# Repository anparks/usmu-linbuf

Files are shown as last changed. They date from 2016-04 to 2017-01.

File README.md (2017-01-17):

This repository contains hardware design files for the uSMU LINBUF project, a test instrument for measuring the time-domain current consumption of low-power loads.

Hardware project files and libraries are in altium/* and are compatible with Altium Designer 14+.

The user's manual is at doc/manual.html, and a PDF printout of the schematics are at doc/schematic.pdf.

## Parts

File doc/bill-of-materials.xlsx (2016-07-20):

Comment | Description | Designator | Footprint | Quantity | Source PN | Detailed Description
Test Point | Test Point, large or small foot prints | AUX_IN, AUX_OUT, EXT_REF | Test Point - Large | 3 | 36-5013-ND | TEST POINT PC MULTI PURPOSE ORG
 |  | GND2, GND4, GND5, GND6 | Test Point - Large | 4 | 36-5011-ND | TEST POINT PC MULTI PURPOSE BLK
 |  | HI_SENSE, LO_SENSE | Test Point - Large | 2 | 36-5010-ND | TEST POINT PC MULTI PURPOSE RED
Cap | Ceramic Capacitor (Surface Mount) | C1, C2 | 1210-W | 2 | 587-2832-1-ND | CAP CER 10UF 35V X5R 1210
Cap | Ceramic Capacitor (Surface Mount) | C3, C4 | ‘0805 | 2 | 587-2400-1-ND | CAP CER 1UF 50V X5R 0603
Cap | Ceramic Capacitor (Surface Mount) | C5 | ‘0805 | 1 | 587-1994-1-ND | CAP CER 0.1UF 35V X5R 0402
2STD16654T4 | STMicroelectronics NPN BJT High Power | Q1 | TO-252 | 1 | 497-5236-1-ND | TRANS NPN 65V 6A DPAK
Res2 | Resistor | Rbuf1 | AXIAL-0.4 | 1 | CMF1.0HHCT-ND | RES 1 OHM 1/2W 1% AXIAL
Res2 | Resistor | Rbuf2 | AXIAL-0.4 | 1 | CMF1.0HHCT-ND | RES 1 OHM 1/2W 1% AXIAL
Res2 | Resistor | Rbuf3 | AXIAL-0.4 | 1 | CMF10.0HFCT-ND | RES 10.0 OHM 1/2W 1% AXIAL
Res2 | Resistor | Rbuf4 | AXIAL-0.4 | 1 | CMF20.0HFCT-ND | RES 20.0 OHM 1/2W 1% AXIAL
Res2 | Resistor | Rbuf5, Rs1 | AXIAL-0.4 | 2 | CMF100HBCT-ND | RES 100 OHM 1/2W 0.1% AXIAL
Res2 | Resistor | Rs2 | AXIAL-0.4 | 1 | CMF200HFCT-ND | RES 200 OHM 1/2W 1% AXIAL
Res2 | Resistor | Rs3 | AXIAL-0.4 | 1 | CMF1.0KHBCT-ND | RES 1.0K OHM 1/2W 0.1% AXIAL
Res2 | Resistor | Rs4 | AXIAL-0.4 | 1 | CMF2.0KHBCT-ND | RES 2.0K OHM 1/2W 0.1% AXIAL
Res2 | Resistor | Rs5 | AXIAL-0.4 | 1 | CMF10.0KHLCT-ND | RES 10.0K OHM 1/2W .1% AXIAL
JS202011CQN | 6-pin DPDT (tied) Slide Switch | SW1, SW2, SW3, SW4, SW5, SW6, SW7 | JS202011CQN | 7 | 401-2001-ND | SWITCH SLIDE DPDT 300MA 6V
MC78M06 | 500mA Positive Voltage Regulator | U1 | TO-252 | 1 | MC78M06CDTRKGOSCT-ND | IC REG LDO 6V 0.5A DPAK
OPA1492 | OPAx192 Op-Amp Texas Instruments | U2 | 14-SOIC-TI | 1 | 296-43159-1-ND | IC OPAMP RRI/O 14SOIC
3339H | Bourns 4-turn Trimpot | VR1 | 3339H | 1 | 3339H-103LF-ND | TRIMMER 10K OHM 0.5W PC PIN
BANANA | Banana plug | GND1, GND3 | BANANA | 2 | BP-B | BANANA JACK BINDING POST, BLACK
 |  | VDD, VOUT1 | BANANA | 2 | BP-R | BANANA JACK BINDING POST, RED

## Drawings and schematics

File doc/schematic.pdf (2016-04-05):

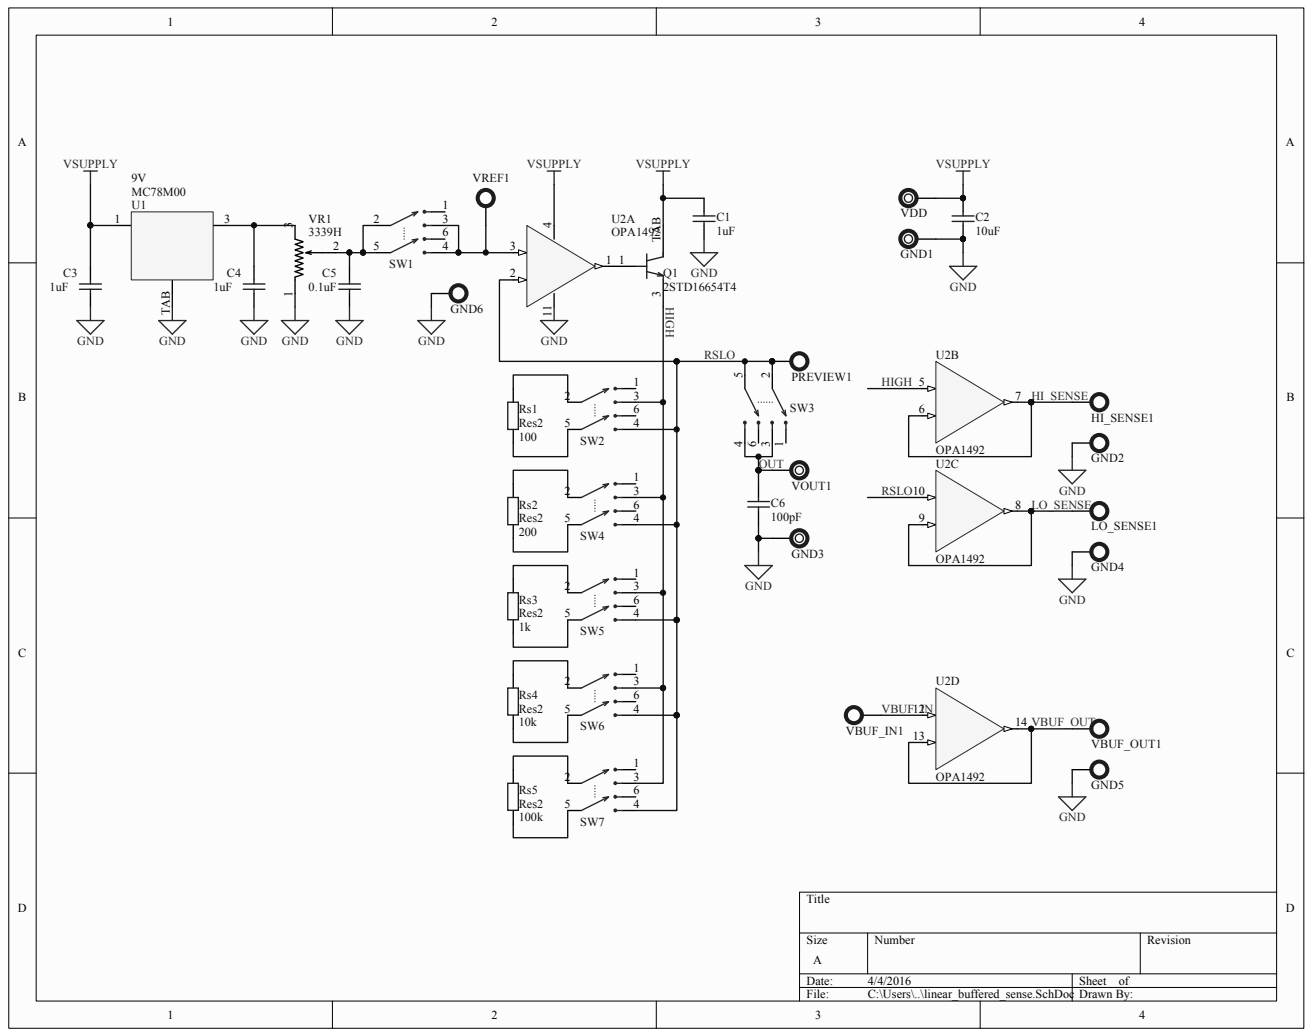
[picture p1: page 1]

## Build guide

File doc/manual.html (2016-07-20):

# uSMU LINBUF User's Guide

github.com/anparks/usmu-linbuf

Click for Schematics

Click for a bill of materials

The uSMU (micro- Source Measure Unit) tools are intended to allow current measurement with a high temporal resolution and high dynamic range.

The uSMU LINBUF tool is a simple implementation of the uSMU with decent dynamic range and good precision.

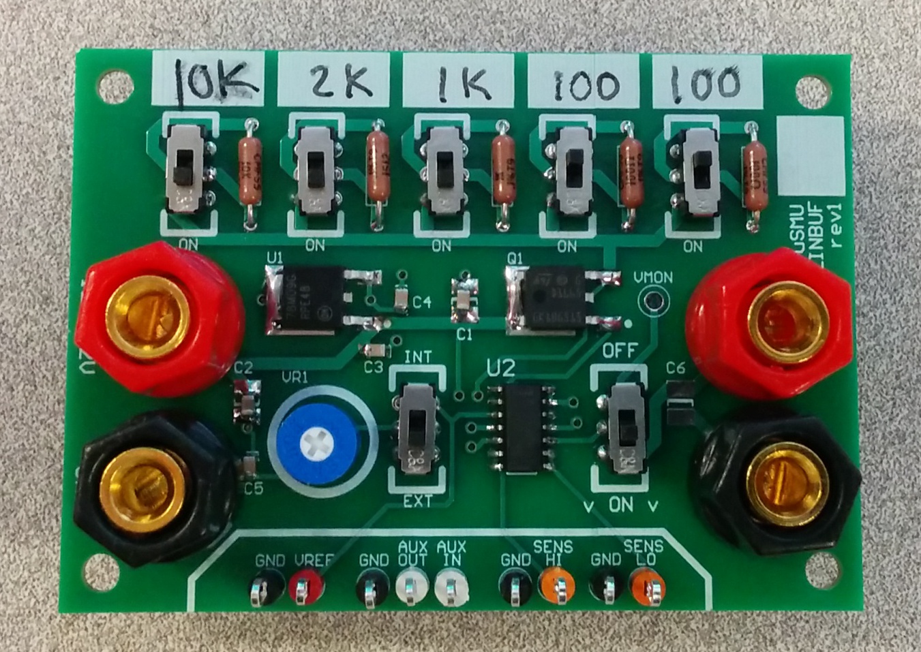
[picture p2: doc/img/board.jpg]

The uSMU LINBUF rev1 hardware

### Theory of operation

The LINBUF tool places one of several high-precision resistors in the output current path of a linear voltage regulator. The voltage across the sense resistor is monitored and gives an indication of current through the load.

This tool is intended to be used in conjunction with an oscilloscope or other data acquisition device (DAQ) with either two channels or one differential input channel. The oscilloscope should monitor the difference between SENS HI and SENS LO voltages. The user should then divide this difference by the value of the selected sense resistor in order to find current through the load.

The input voltage for the LINBUF device must be between 12 and 32V, in order to meet the needs of the onboard 9V reference generator and to comply with the maximum voltage and power ratings of all components.

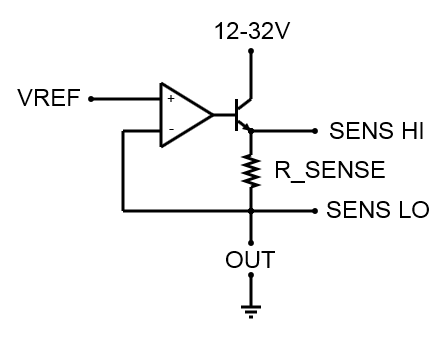
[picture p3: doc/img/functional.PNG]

A functional diagram of the uSMU LINBUF rev1

### Warnings

- The LINBUF has no current limiting or fault protection... Always use a current-limited power supply, and set the lowest possible limit
- Reversing the power supply polarity, even for a moment, may damage the uSMU or your load
- Do NOT change any other switch positions when the output enable switch is ON

### Step-by-step: Using the uSMU LINBUF

1. Attach oscilloscope or DAQ to LINBUF sense output
Connect Ch1 of your oscilloscope or DAQ between SENS_HI and GND, and Ch2 between SENS_LO and GND.

NEVER attach one standard oscilloscope probe between SENS_HI and SENS_LO, or connect either SENS_HI or SENS_LO to the ground of your DAQ, as this will destroy the uSMU and/or your oscilloscope/DAQ. However, a differential probe or DAQ input may be connected across SENS_HI and SENS_LO.

2. Attach a power supply
MAKE SURE the output enable switch is in the OFF position before connecting a power supply. Set a 500mA or lower current limit on a 12-32V benchtop power supply and connect it between the GND and 12-32V inputs on the left side of the LINBUF board. Higher supply voltages will improve the dynamic range of LINBUF current measurement as detailed in the "Output current limits" section.

3. Select a sense resistor value
Higher sense resistor values give better current resolution, while lower sense resistor values give a higher peak current limit. Enable a sense resistor value by turning the corresponding switch to the "ON" position. If multiple resistors are enabled, they will be placed in parallel and so the parallel combination should be computed.

3. Set output voltage (reference voltage)
Now configure the voltage that will be supplied to the device you'd like to monitor. The LINBUF can either generate it's own adjustable reference voltage (0-8V) or be used with an external reference voltage supplied on the VREF pin.

To use the internal reference, set the reference selection switch to INT. Now connect a voltmeter to the VMON test point and use a screwdriver to rotate the wiper of the reference-adjust trimpot VR1 in order to set the desired voltage. Be certain your output enable is OFF during this adjustment, or that your load is not connected. Do not connect anything to the VREF pin when using an internally generated reference voltage.

To use the external reference, set the reference selection switch to EXT. Now connect your desired reference voltage source between the VREF and GND pins. The reference voltage may be from 0V to around 2V below the supply voltage you are using.

***Be sure to disconnect your voltmeter from VMON before moving to the next step. Current flowing to your voltmeter will cause an error in load current measurement.

4. Connect the LINBUF output to the load device
The output terminals OUT+ and GND may be connected to the supply rails of the device you'd like to monitor.

5. Connect the auxiliary buffer (optional)
The LINBUF provides an extra buffer for performing isolated voltage measurements of your device under test. The AUX_IN pin may be connected to any digital or analog node in your device under test, provided that node's voltage will not exceed the supply rail of the LINBUF. The AUX_OUT can then be connected to your oscilloscope.

6. Enable the output, and capture data
Switch the output enable switch to the ON position to supply your device under test.

Capture a trace on your oscilloscope or DAQ, and process it to compute load current. The load current may be computed as (SENS_HI - SENS_LO) / (R_SENSE)

### Output current limits

The maximum sourced current capability of the LINBUF is dependent on it's configuration. Factors to consider include:

1. The supply voltage used
2. The reference (output) voltage selected
3. The sense resistor value and power rating
4. The transistor switch power rating

Generally speaking, the following will be true:

Continuous current capability = sqrt((R_sense power rating) / (R_sense value))

Peak current limit* = (V_source - V_ref)/ (R_sense value)
*Peak current value is NOT sustainable due to component overheating

As an example, for a 100 Ohm 1/2 Watt sense resistor, a 32V source voltage, and a 2V output voltage, the LINBUF can source up to 70mA continuously and will limit peaks that are higher than around 300mA.

### Precision and accuracy

The precision of the uSMU LINBUF will be dependent on the sense resistor used, and the resolution of the oscilloscope or data acquisition device used. The sense resistor value provides the current-to-voltage conversion gain. For example, a 1k Ohm sense resistor will generate a 1V output differential between SENS HI and SENS LO for every 1mA of current consumed by the load, meaning an oscilloscope with a 10mV resolution will resolve changes in load current as small as 10uA.

Assuming an accurate oscilloscope or DAQ, accuracy of the uSMU LINBUF is dependent on two factors:

1. The additional current paths produced by buffer inputs
2. The input offset voltages of the buffer amplifiers used to detect voltages at SENS HI and SENS LO

Generally speaking, the accuracy will be better than the minimal resolution of the measurement equipment.

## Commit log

2016-03-27 initial commit, imported libraries from wisp
    [linear_buffered_sense.SchDoc, main.PcbDoc, usmu.PrjPcb]
2016-03-27 Slight folder restructure
    [usmu.PrjPcb]
2016-03-28 First draft of schematic
    [linear_buffered_sense.SchDoc, usmu.PrjPcb]
2016-03-28 Modified Vref decoupling and changed component names
    [linear_buffered_sense.SchDoc, usmu.PrjPcb]
2016-03-28 Added small decoupling cap directly at output regulator
    [linear_buffered_sense.SchDoc]
2016-03-28 Fixed footprint association issue
    [linear_buffered_sense.SchDoc]
2016-03-28 Added all components to first draft PCB successfully
    [main.PcbDoc]
2016-03-28 Added all components to PCB. No traces routed.
    [main.PcbDoc]
2016-03-28 Using bananas instead of testpoints on input side
    [linear_buffered_sense.SchDoc, main.PcbDoc]
2016-03-28 Component placement draft done. No traces routed.
    [linear_buffered_sense.SchDoc, main.PcbDoc]
2016-03-28 Routing started
    [linear_buffered_sense.SchDoc, main.PcbDoc]
2016-03-28 First draft of PCB complete. Needs review
    [linear_buffered_sense.SchDoc, main.PcbDoc, usmu.PrjPcb]
2016-03-28 Slight updates. Ready to ship rev1
    [main.PcbDoc]
2016-03-28 Created outline as requested by sunstone
    [main.PcbDoc]
2016-04-05 Added gerbers and changed readme, added schematic pdf
    [main.GBL, main.GBO, main.GBP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]
2016-04-25 Fixed CW/CCW pin flip in trimpot footprint
    [linear_buffered_sense.SchDoc]
2016-04-25 Tore up all traces in prep for major changes for rev2
    [main.PcbDoc]
2016-04-27 Aux in/out text labels were reversed. Fixed.
    [main.PcbDoc, usmu.PrjPcb]
2016-05-12 Updated schematic with rev2 changes. Moving on to layout.
    [linear_buffered_sense.SchDoc, main.PcbDoc]
2016-05-12 Layout seemingly done for rev2. Needs review.
    [linear_buffered_sense.SchDoc, main.PcbDoc, usmu.PrjPcb]
2016-07-20 Added Bill of Materials
    [bill-of-materials.xlsx]
2016-07-20 Removed gerbers - versioning is confusing with them in there
    [main.GBL, main.GBO, main.GBP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]
